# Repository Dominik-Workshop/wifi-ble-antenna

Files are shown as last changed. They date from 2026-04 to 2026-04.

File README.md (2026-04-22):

# WiFi BLE Antenna

 

<p align="center">
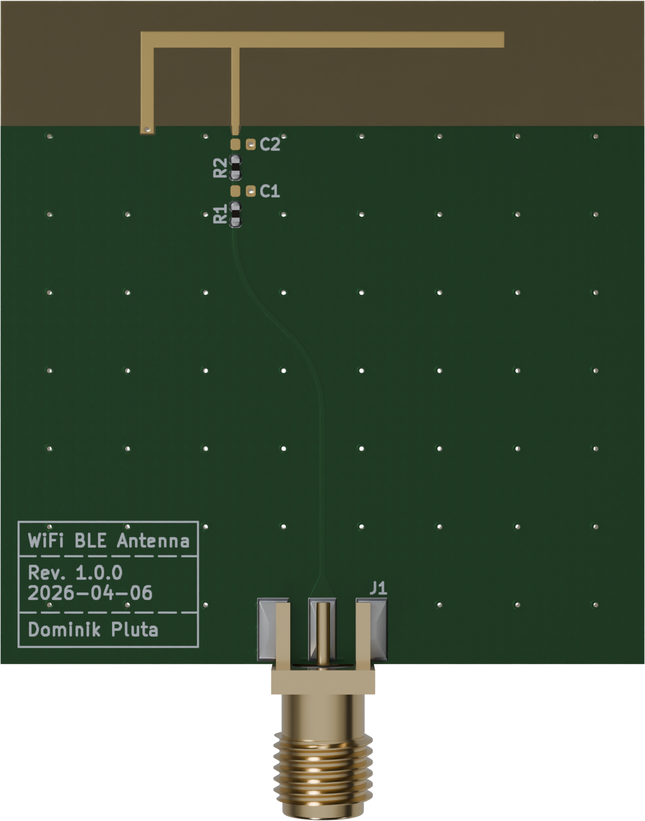
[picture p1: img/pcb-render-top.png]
Hero image
  
</p>

## Antenna Design

Dimensioning of the antenna simulated in [antenna-design.mat](antenna-design.mat):

<p align="center">
  
</p>

### Geometry Parameters
The following parameters (in mm) define the physical layout and PCB dimensions:

| Parameter | Value | Expression / Derived Value |
| :--- | :--- | :--- |
| **D1** | 9 | - |
| **D2** | 2 | - |
| **D3** | 9 | - |
| **D4** | 5 | - |
| **D5** | 17 | - |
| **D6** | 0.5 | - |
| **D7** | 34.5 | - |
| **W1** | 0.8 | - |
| **W2** | 0.5 | - |
| **W3** | 1 | - |
| **L1** | 5.5 | - |
| **L2** | 5.5 | - |
| **L3** | 23.3 | `W1 + D4 + W2 + D5` |
| **PCBwidth** | 42.5 | `D7 + L1 - D6 + W3 + D2` |
| **PCBlength** | 41.3 | `D1 + L3 + D3` |
| **CopperToEdge** | 0.5 | - |

## Simulation Results

### Mesh Settings

To ensure accurate simulation of the resonance and impedance, the following manual meshing parameters were used:

* **Max Edge Length:** `0.025 m` (25 mm)
* **Min Edge Length:** `0.004 m` (4 mm)
* **Growth Rate:** `0.4`

<p align="center">
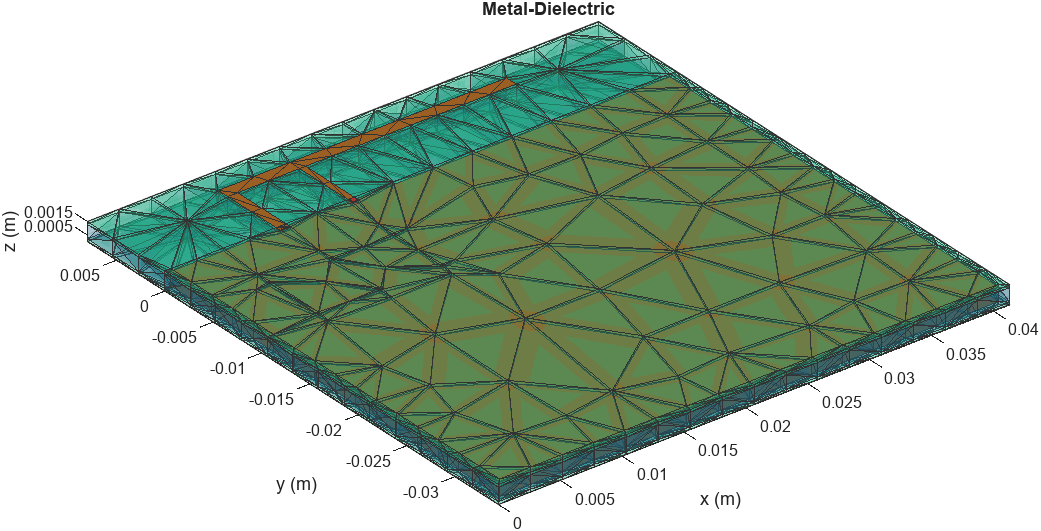
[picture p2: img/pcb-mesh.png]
PCB Mesh geometry
  
</p>

### Return Loss (S11) & Impedance (Z)

Simulated **2.3 - 2.7 GHz** range (`linspace(2.3, 2.7, 80)`):

<p>
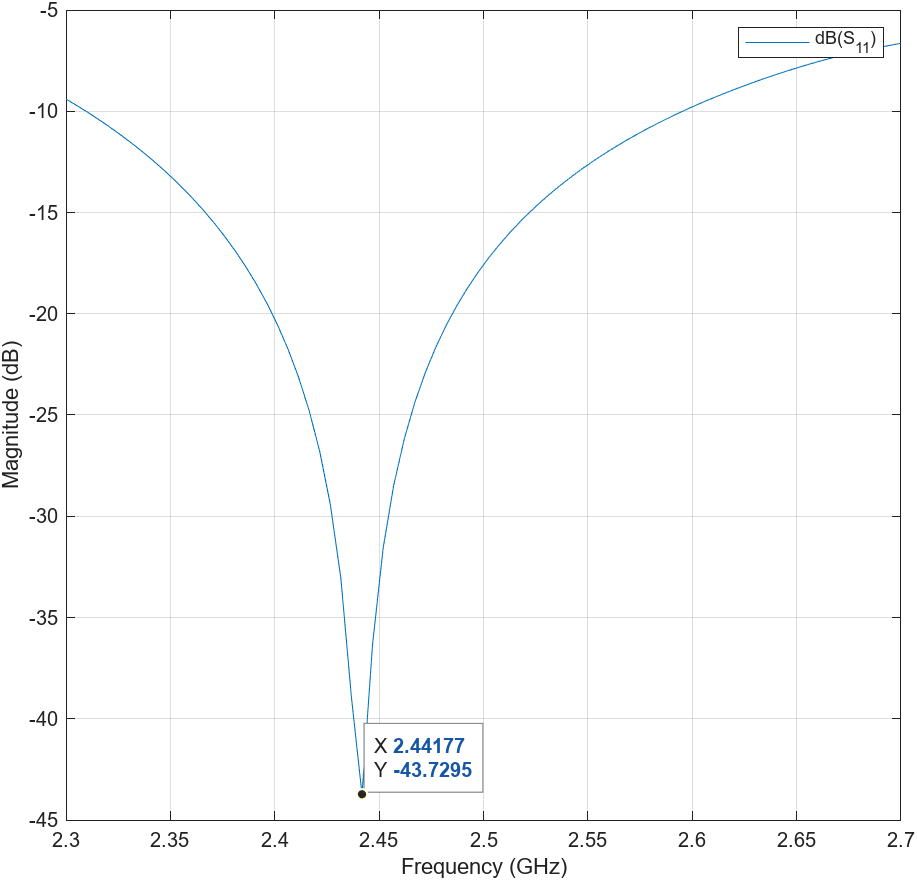
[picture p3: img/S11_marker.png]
S11 Return Loss
  
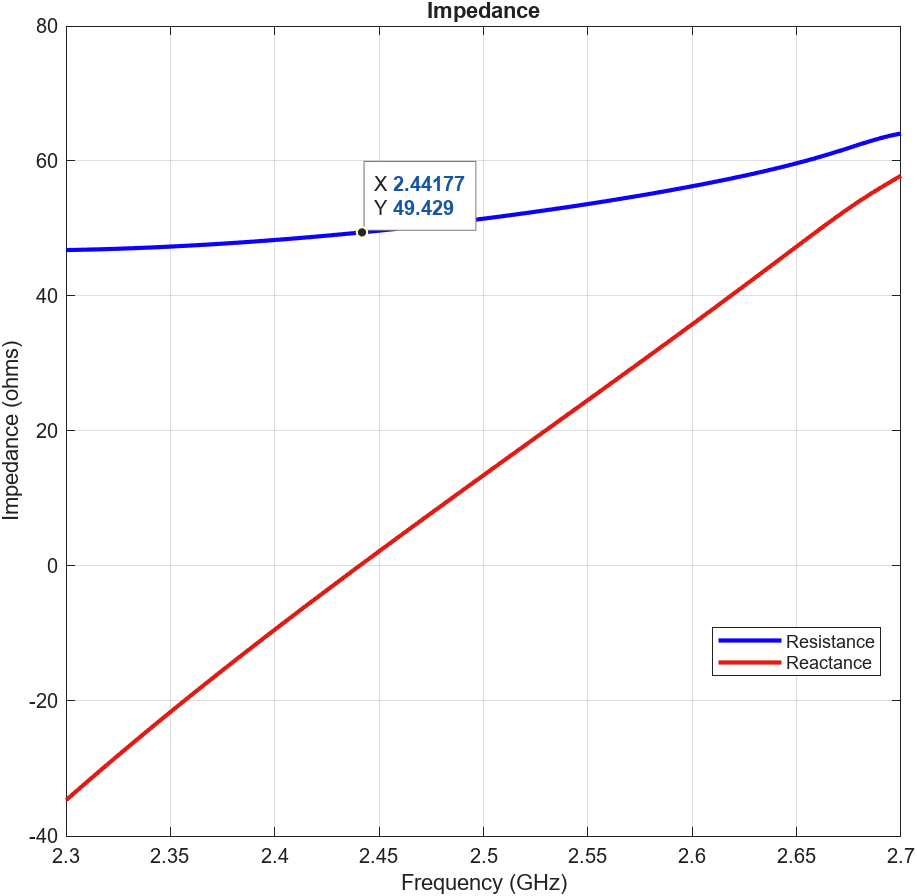
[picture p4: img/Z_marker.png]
Impedance
  
</p>

### Current Distribution

Surface current distribution along the antenna traces at the target resonance:

<p align="center">
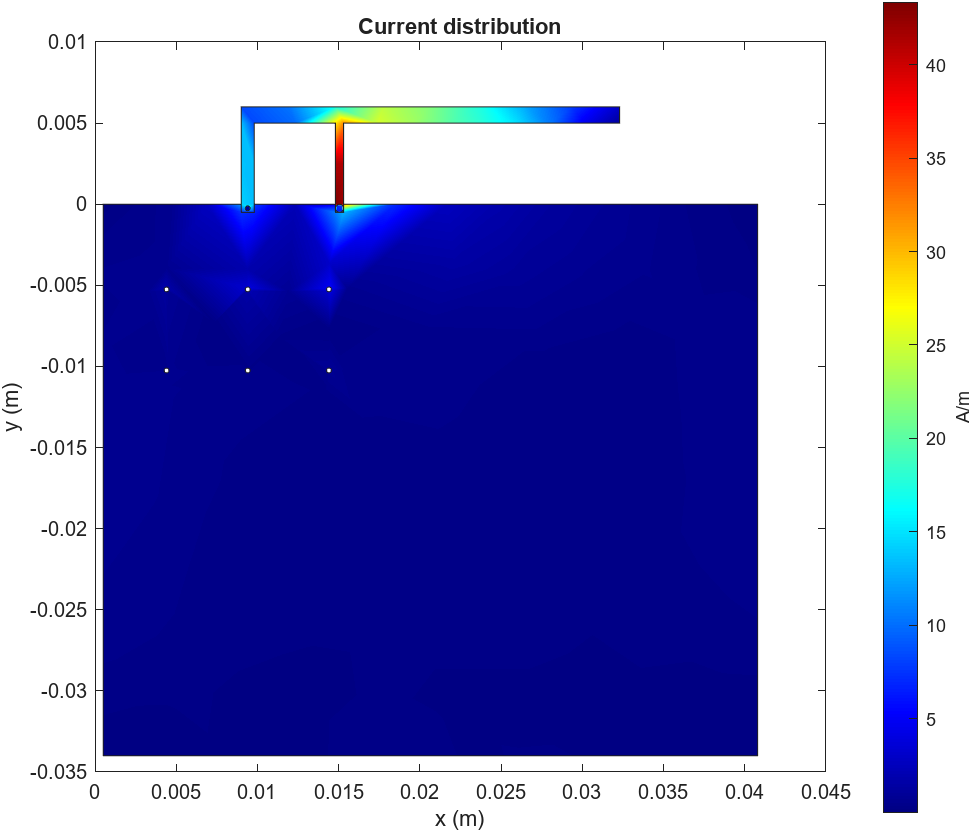
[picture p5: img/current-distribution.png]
Surface Current Distribution
  
</p>

### Radiation Pattern
2D Azimuth (AZ) and Elevation (EL) far-field radiation patterns:

<p>
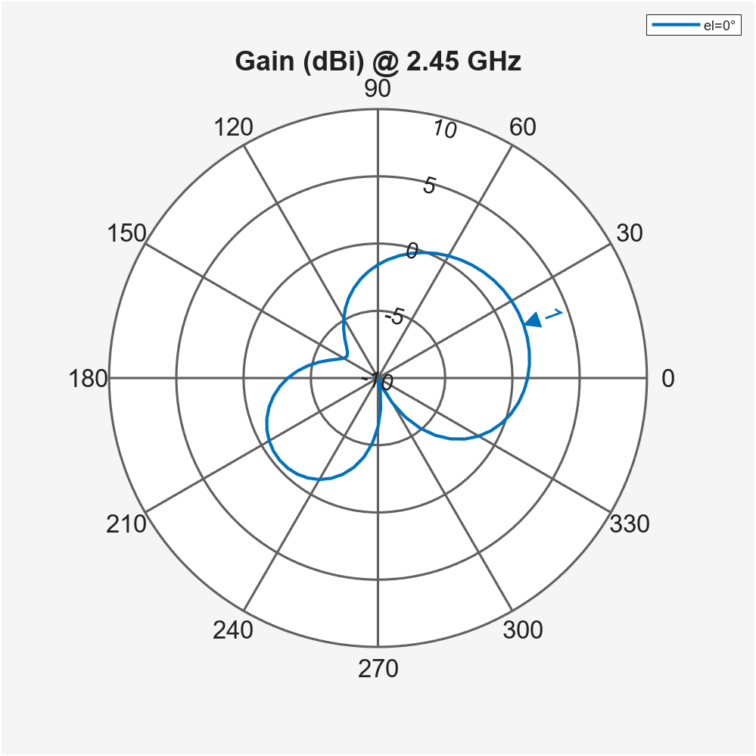
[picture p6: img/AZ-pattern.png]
Azimuth Pattern
  
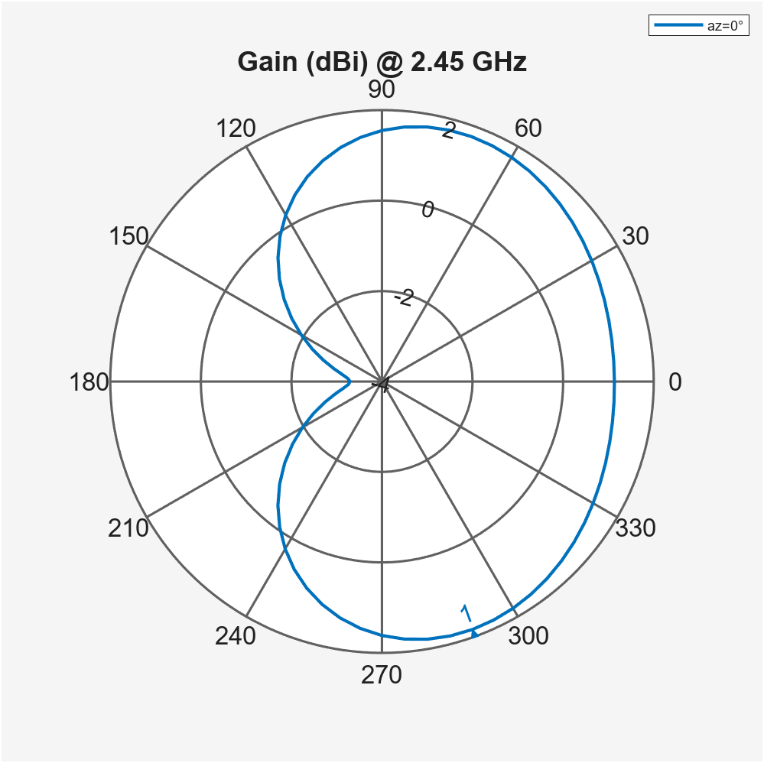
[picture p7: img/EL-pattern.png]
Elevation Pattern
  
</p>

## Project Status

**Design:** ✅ --> **Fabrication & Assembly:** ✅ --> **Bring-up & Tuning:** ⌛

The project has been assembled and tested. It works, but still needs tuning to meet the target impedance and desired frequency range.
(Note: manufacturing tolerances play a big role in antenna performance.)

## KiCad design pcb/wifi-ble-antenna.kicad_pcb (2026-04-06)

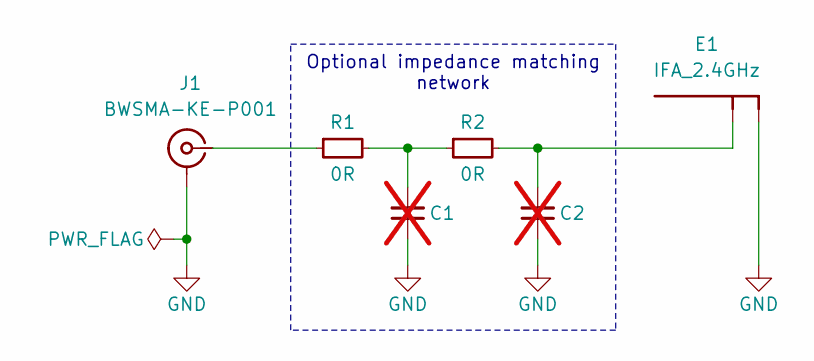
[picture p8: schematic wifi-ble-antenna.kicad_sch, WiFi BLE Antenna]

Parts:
C1, C2: C-0402-template; C_0402_1005Metric; Tolerance Tolerance; Voltage Voltage; MPN MPN; LCSC #LCSC; not fitted
E1: IFA_2.4GHz; Antenna_Custom_IFA_2.4GHz
J1: BWSMA-KE-P001; Conn_SMA_BWSMA-KE-P001; MPN BWSMA-KE-P001; LCSC C496550
R1, R2: R-0R-0402; R_0402_1005Metric; Tolerance 1%; MPN 0402WGF0000TCE; LCSC C17168

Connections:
GND: C1.1, C2.1, E1.2 (GND), J1.2
unnamed: C1.2, R1.2, R2.1
unnamed: C2.2, E1.1 (SIG), R2.2
unnamed: J1.1, R1.1

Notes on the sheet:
Optional impedance matching network

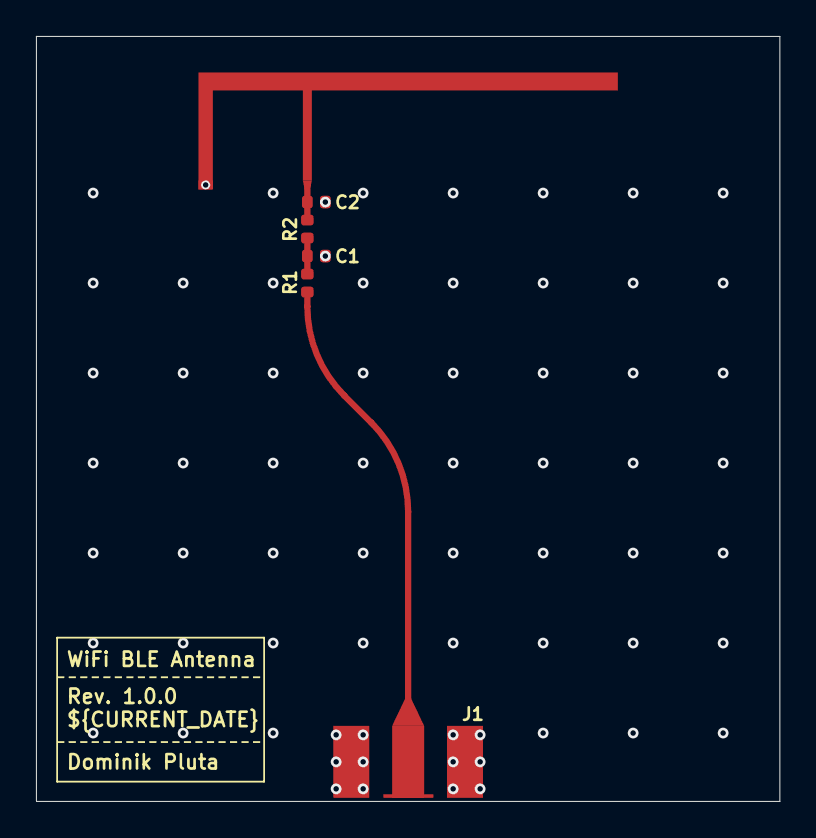
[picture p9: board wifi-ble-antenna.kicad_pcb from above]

Board: 4 copper layers, 41.3 x 42.5 mm, 6 parts (0 on the bottom side), 4 nets.

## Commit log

2026-03-14 Initialize PCB project
    [wifi-ble-antenna.kicad_pcb, wifi-ble-antenna.kicad_sch]
2026-03-14 Sch: Add optional antenna matching network
    [wifi-ble-antenna.kicad_sch]
2026-03-14 Sch: Add SMA connector and antenna, finish schematic
    [wifi-ble-antenna.kicad_sch]
2026-03-27 PCB: Define stackup and pre-defined sizes, init PCB layout
    [wifi-ble-antenna.kicad_pcb, wifi-ble-antenna.kicad_sch]
2026-04-04 Add antenna dimensioning diagram in README
2026-04-04 Sim: Define PCB dimensions and IFA shape parametricly
2026-04-04 Sim: Define all PCB stackup layers
2026-04-04 Sim: Add GND plane on In1_Cu layer
2026-04-04 Sim: Add feed point and GND via
2026-04-04 Sim: Generate script from the PCB design toolbox
2026-04-04 Sim: Add GND on In2.Cu, add some stitching vias, tune the IFA initially
2026-04-04 Sim: Tune the antenna to around 2.46GHz: S11 -34dB, 48Ohm
2026-04-05 PCB: Add IFA, initial layout
    [wifi-ble-antenna.kicad_pcb]
2026-04-05 PCB: Finalize layout - add impedance matching geometry to SMA, ensure dimensions are as designed
    [wifi-ble-antenna.kicad_pcb, wifi-ble-antenna.kicad_sch]
2026-04-05 PCB: Add stackup table, origin points, cleanup silkscreen, add via stitching
    [wifi-ble-antenna.kicad_pcb]
2026-04-05 Add PCB render in README, remove WIP note, add project status section
2026-04-05 PCB: Match PCB dimensions exactly with the simulations
    [wifi-ble-antenna.kicad_pcb]
2026-04-05 PCB: Remove solder mask from the antenna
    [wifi-ble-antenna.kicad_pcb]
2026-04-05 Update PCB render
2026-04-05 Show CopperToEdge clearance on the antenna dimensioning diagram
2026-04-06 Clear ERC and DRC
    [wifi-ble-antenna.kicad_pcb, wifi-ble-antenna.kicad_sch]
2026-04-06 PCB: Move matching network closer to the antenna element
    [wifi-ble-antenna.kicad_pcb]
2026-04-06 PCB: Remove soldermask from top and bottom area aroud the antenna
    [wifi-ble-antenna.kicad_pcb]
2026-04-06 PCB: Move the PCB info block on silkscreen
    [wifi-ble-antenna.kicad_pcb]
2026-04-06 Sim: Update generated script from the PCB Antenna Designer toolbox
